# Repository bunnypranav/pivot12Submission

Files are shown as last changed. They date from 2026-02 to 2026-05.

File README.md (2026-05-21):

# PIVOT 12
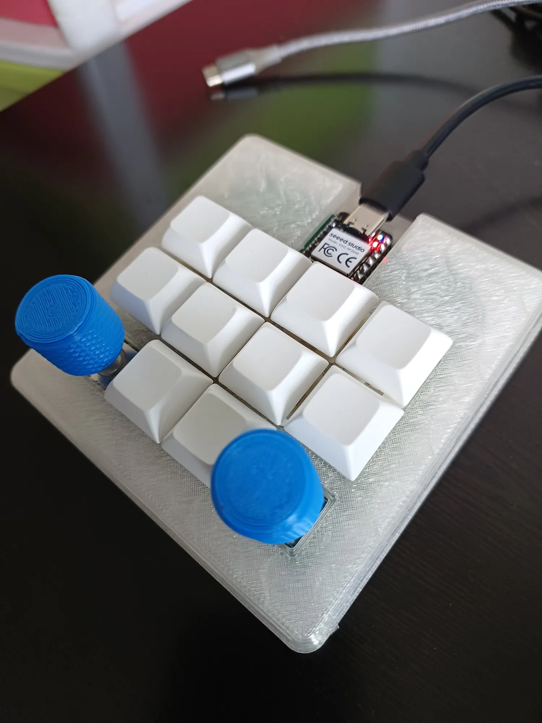
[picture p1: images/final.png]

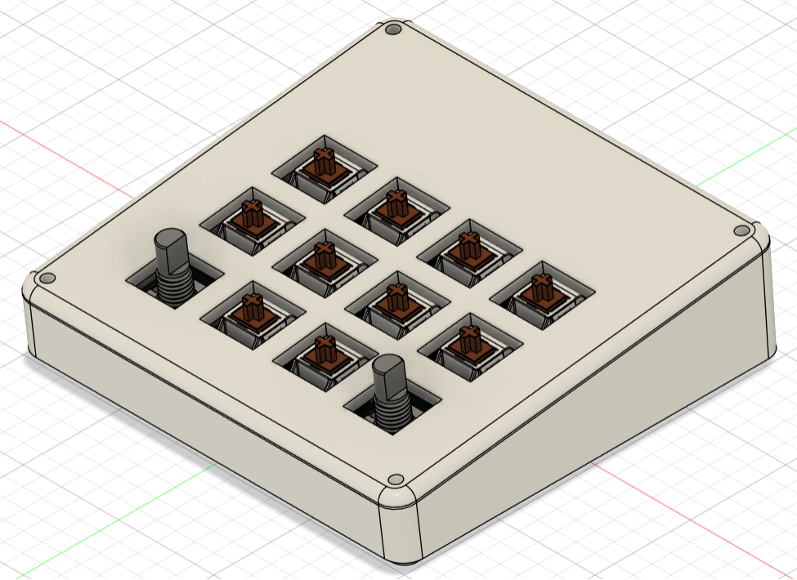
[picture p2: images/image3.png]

PIVOT 12 is a macropad with 10 MX switches and two rotary encoders and uses QMK firmware. It is aimed for productivity with a huge focus on the two dials. The name "PIVOT" signifies the rotary encoders as "pivotal" control elements (*pun intended*). The "12" in the name refers to the total number of inputs (10 switches + 2 rotary encoders) on the macropad.

A lot of what I do involves switching tabs, scrolling, navigating files, adjusting volume, and triggering similar shortcuts. Instead of just keys, I wanted something that felt like a control panel, and that is where the two dials come in. One usually handles navigation (like horizontal scrolling or tab switching), and the other handles adjustments (volume, zoom, etc.). Each encoder also has a push button, so they're more than just scroll wheels.

Building this was a great learning experience. I designed the PCB in KiCad and the case in Fusion 360. It was my first time designing a PCB, and I definitely struggled, and learned a lot. The case design was also a fun challenge, especially with the incline and making sure everything fit properly and was compatible with the PCB.

# Features
* 10 MX switches
* 2 Rotary Encoders
* Case with a 7° incline for ergonomic use

# PCB
*Made in KiCad*
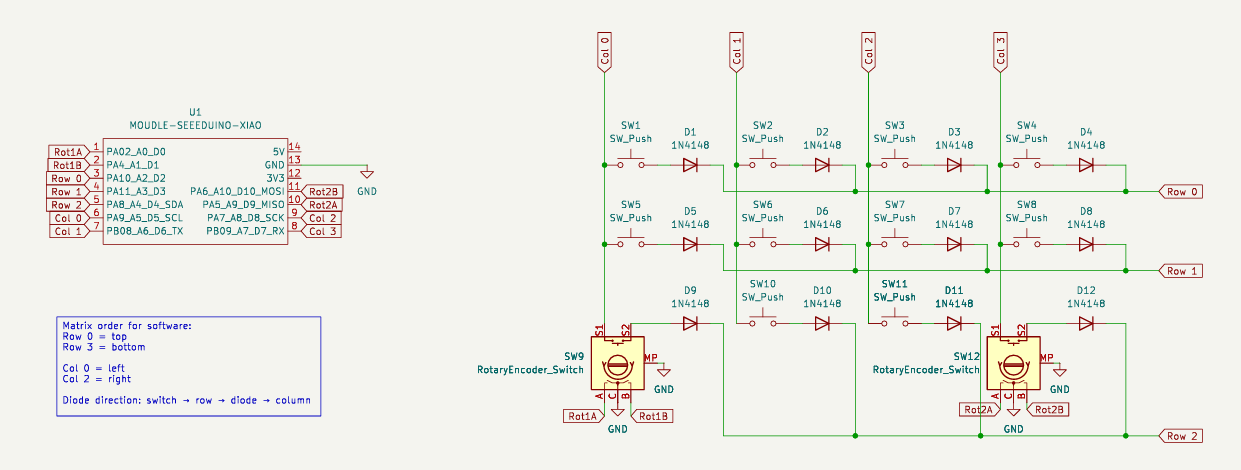
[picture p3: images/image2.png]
Schematic

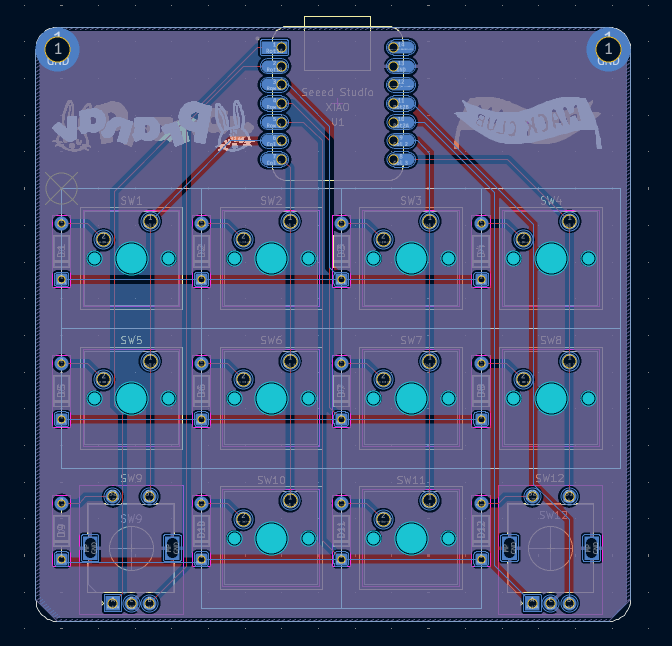
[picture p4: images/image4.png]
PCB Design

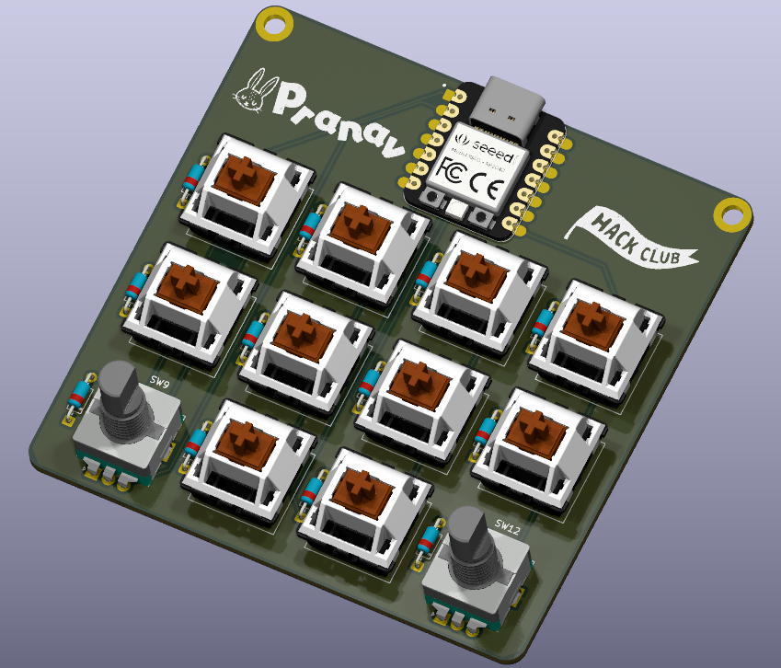
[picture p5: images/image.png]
3D PCB


# CAD Model
*Made in Fusion 360*
I didn't want a flat box, so I added a 7° incline. It's subtle, but it makes a noticeable difference when using it for long periods. The incline feels natural without making the device bulky.

For a video, see https://github.com/bunnypranav/pivot12Submission/raw/refs/heads/main/images/caseVid.mp4

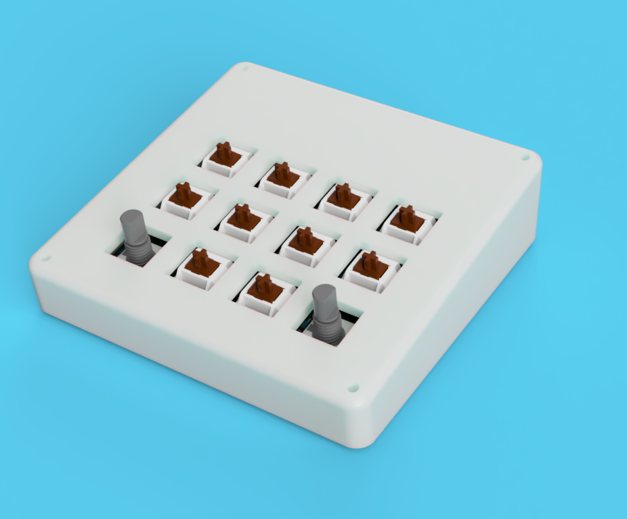
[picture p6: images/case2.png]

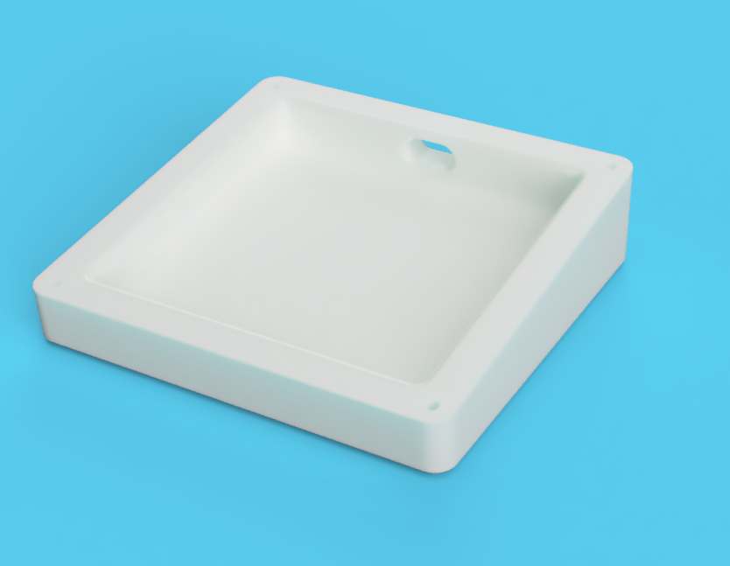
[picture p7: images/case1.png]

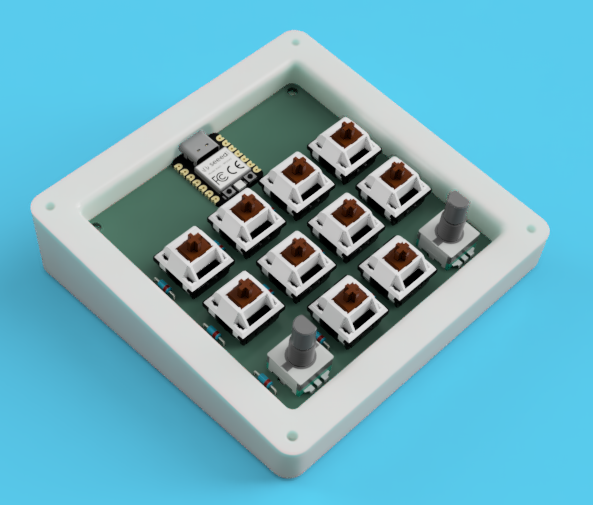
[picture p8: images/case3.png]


# BOM:
* 1x XIAO RP2040
* 10x Cherry MX Switches
* 10x DSA Keycaps
* 2x EC11 Rotary Encoder
* 12x 1N4148 DO-35 Diodes.
* 4x M3x5x4 Heatset inserts
* 4x M3x16mm SHCS Bolts
* 1x PCB: Costs about USD 14 with shipping
* 1x Case (4 printed parts)
  * Bottom base
  * Top plate
  * 2x Knurled knobs for dials

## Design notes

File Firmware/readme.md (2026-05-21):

# pivot12

pivot12

*A short description of the keyboard/project*

* Keyboard Maintainer: [Bunny Pranav](https://github.com/bunnypranav)
* Hardware Supported: *The PCBs, controllers supported*
* Hardware Availability: *Links to where you can find this hardware*

Make example for this keyboard (after setting up your build environment):

    make pivot12:default

Flashing example for this keyboard:

    make pivot12:default:flash

See the [build environment setup](https://docs.qmk.fm/#/getting_started_build_tools) and the [make instructions](https://docs.qmk.fm/#/getting_started_make_guide) for more information. Brand new to QMK? Start with our [Complete Newbs Guide](https://docs.qmk.fm/#/newbs).

## Bootloader

Enter the bootloader in 3 ways:

* **Bootmagic reset**: Hold down the key at (0,0) in the matrix (usually the top left key or Escape) and plug in the keyboard
* **Physical reset button**: Briefly press the button on the back of the PCB - some may have pads you must short instead
* **Keycode in layout**: Press the key mapped to `QK_BOOT` if it is available

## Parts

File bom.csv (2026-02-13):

Item | Quantity | Price with Shipping ($)
Seeed XIAO RP2040 | 1 | Part of KIT
MX-Style switches | 10 | Part of KIT
White blank DSA keycaps | 10 | Part of KIT
EC11 Rotary encoders | 2 | Part of KIT
1N4148 Diodes | 12 | Part of KIT
M3x5x4 Heatset inserts | 4 | Part of KIT
M3x16mm screws | 4 | Part of KIT
PCB | 1 | 14
Case (4 printed parts) | 1 | Printing legion, shipping about 1.1USD

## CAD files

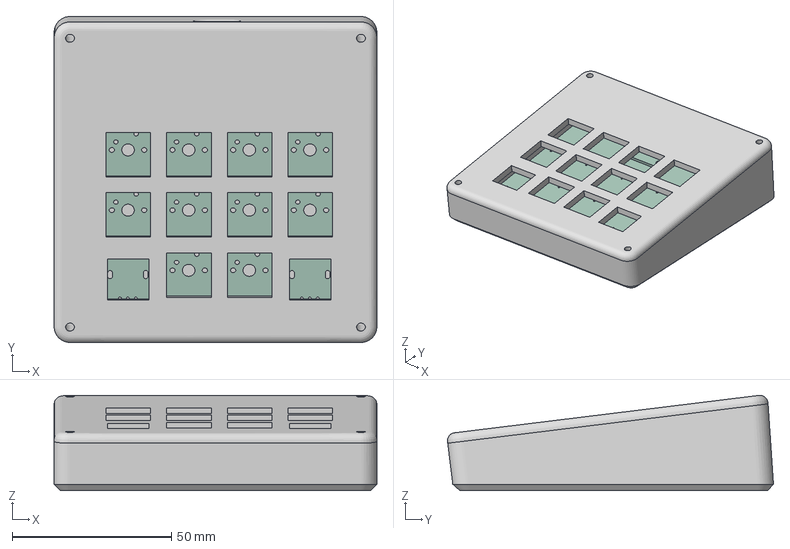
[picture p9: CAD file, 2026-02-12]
CAD/PIVOT-12-Case.3mf
101.4 x 102.4 x 29.9 mm
Base
PCB(NoPrint)
Plate

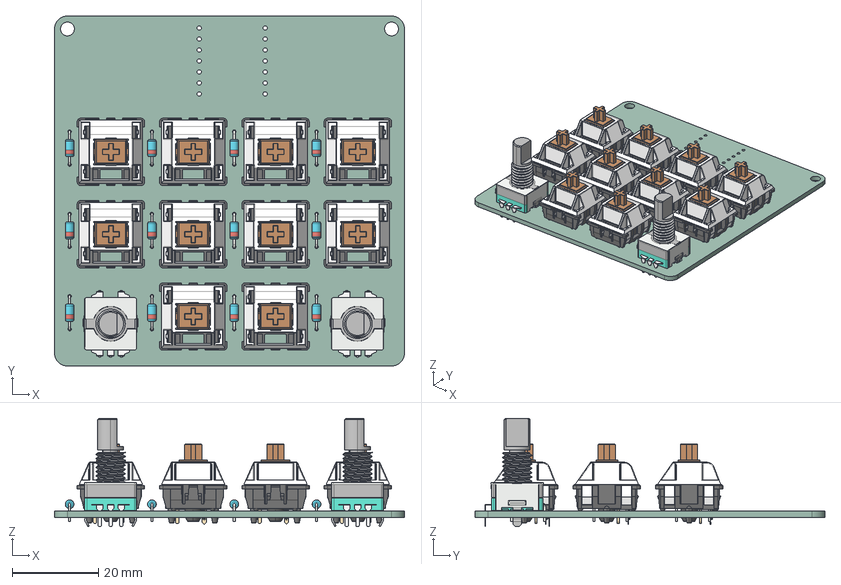
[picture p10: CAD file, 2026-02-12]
PCB/pivot12PCB.step
81.0 x 81.0 x 25.1 mm
D_DO-35_SOD27_P7.62mm_Horizontal x 12
SW_Cherry_MX_1.00u_PCB x 10
Rotary x 2
pivot12KiCadProject_PCB

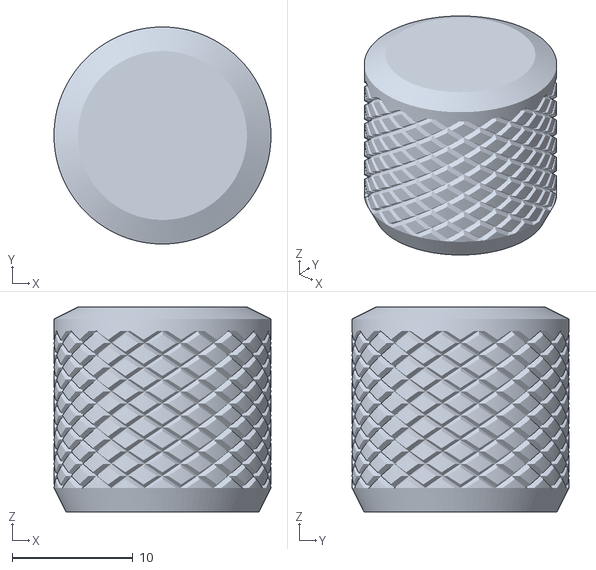
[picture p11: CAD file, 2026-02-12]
production/Knob(x2).stl
18.0 x 18.0 x 17.0

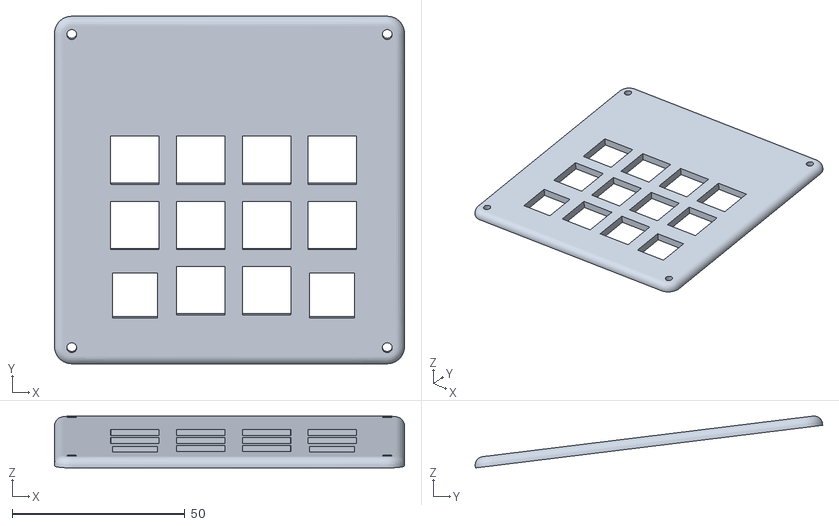
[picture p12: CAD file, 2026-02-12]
production/Top.stl
101.4 x 100.7 x 15.0

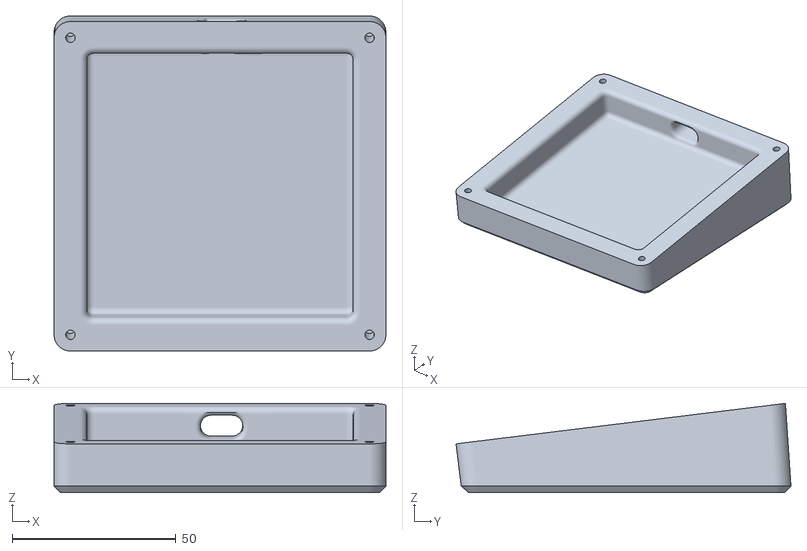
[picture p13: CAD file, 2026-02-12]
production/Base.stl
101.4 x 102.3 x 27.2

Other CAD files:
CAD/PIVOT-12-Case.f3z

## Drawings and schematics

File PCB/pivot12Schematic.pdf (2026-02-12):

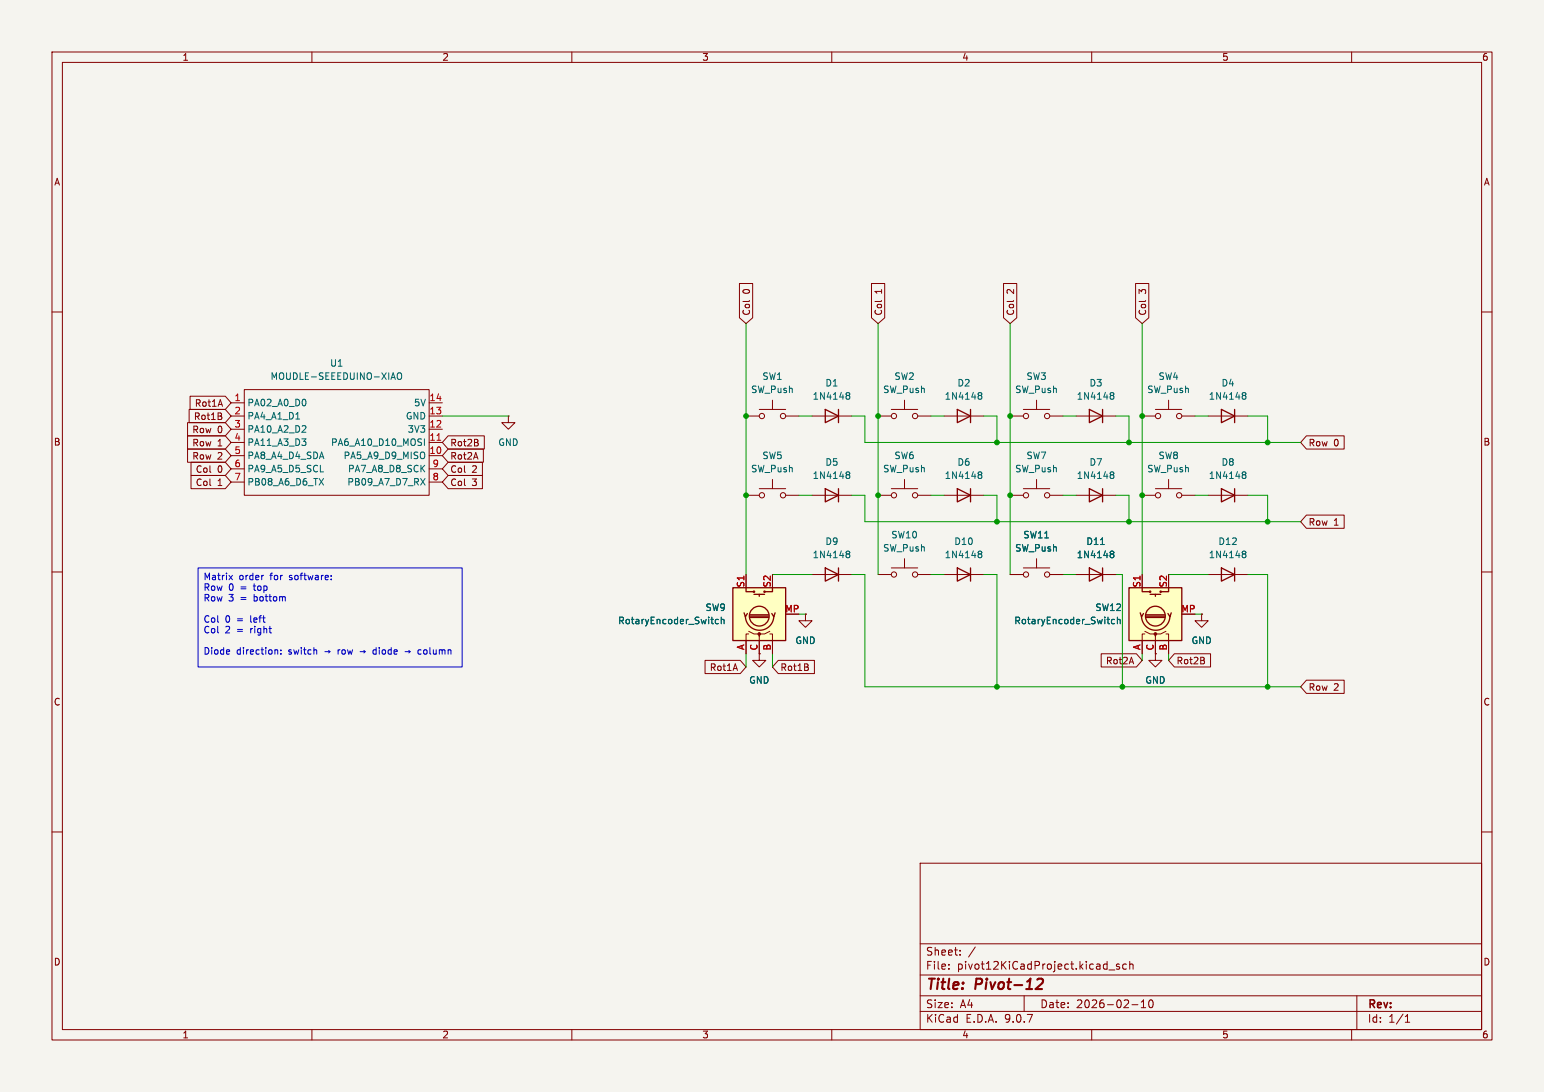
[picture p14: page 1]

Row 1 Rot1B Rot1A Row 0 Row 2 Col 1 Col 0 Matrix order for software: Row 0 = top Row 3 = bottom

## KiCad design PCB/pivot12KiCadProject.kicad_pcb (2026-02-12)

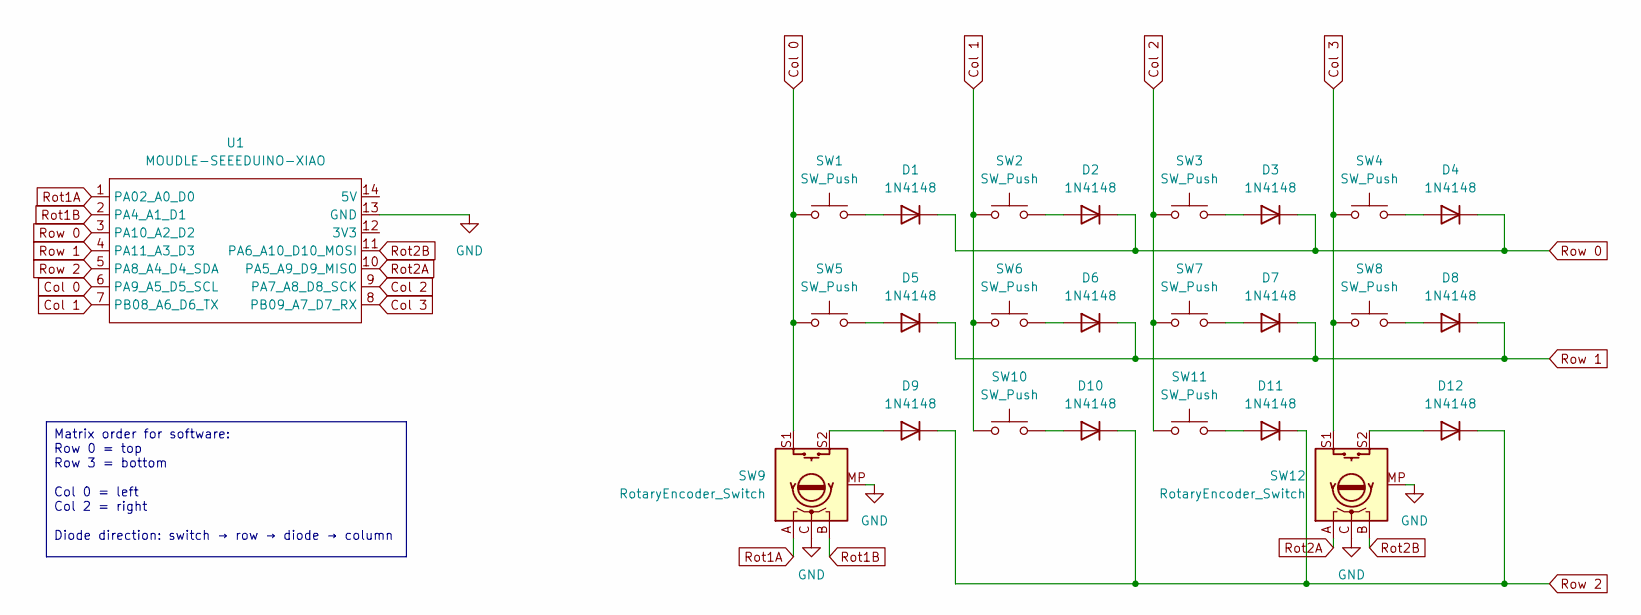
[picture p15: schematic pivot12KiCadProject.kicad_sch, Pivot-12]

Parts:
D1, D2, D3, D4, D5, D6, D7, D8, D9, D10, D11, D12: 1N4148; D_DO-35_SOD27_P7.62mm_Horizontal
SW1, SW2, SW3, SW4, SW5, SW6, SW7, SW8, SW10, SW11: SW_Push; SW_Cherry_MX_1.00u_PCB
SW9, SW12: RotaryEncoder_Switch; RotaryEncoder_Alps_EC11E-Switch_Vertical_H20mm
U1: MOUDLE-SEEEDUINO-XIAO; XIAO-Generic-Hybrid-14P-2.54-21X17.8MM

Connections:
Col 0: SW1.1, SW5.1, SW9.S1, U1.6 (PA9_A5_D5_SCL)
Col 1: SW2.1, SW6.1, SW10.1, U1.7 (PB08_A6_D6_TX)
Col 2: SW3.1, SW7.1, SW11.1, U1.9 (PA7_A8_D8_SCK)
Col 3: SW4.1, SW8.1, SW12.S1, U1.8 (PB09_A7_D7_RX)
GND: SW9.C, SW9.MP, SW12.C, SW12.MP, U1.13 (GND)
unnamed: D1.2 (A), SW1.2
unnamed: D2.2 (A), SW2.2
unnamed: D3.2 (A), SW3.2
unnamed: D4.2 (A), SW4.2
unnamed: D5.2 (A), SW5.2
unnamed: D6.2 (A), SW6.2
unnamed: D7.2 (A), SW7.2
unnamed: D8.2 (A), SW8.2
unnamed: D9.2 (A), SW9.S2
unnamed: D10.2 (A), SW10.2
unnamed: D11.2 (A), SW11.2
unnamed: D12.2 (A), SW12.S2
Rot1A: SW9.A, U1.1 (PA02_A0_D0)
Rot1B: SW9.B, U1.2 (PA4_A1_D1)
Rot2A: SW12.A, U1.10 (PA5_A9_D9_MISO)
Rot2B: SW12.B, U1.11 (PA6_A10_D10_MOSI)
Row 0: D1.1 (K), D2.1 (K), D3.1 (K), D4.1 (K), U1.3 (PA10_A2_D2)
Row 1: D5.1 (K), D6.1 (K), D7.1 (K), D8.1 (K), U1.4 (PA11_A3_D3)
Row 2: D9.1 (K), D10.1 (K), D11.1 (K), D12.1 (K), U1.5 (PA8_A4_D4_SDA)

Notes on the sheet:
Matrix order for software: Row 0 = top Row 3 = bottom Col 0 = left Col 2 = right Diode direction: switch → row → diode → column

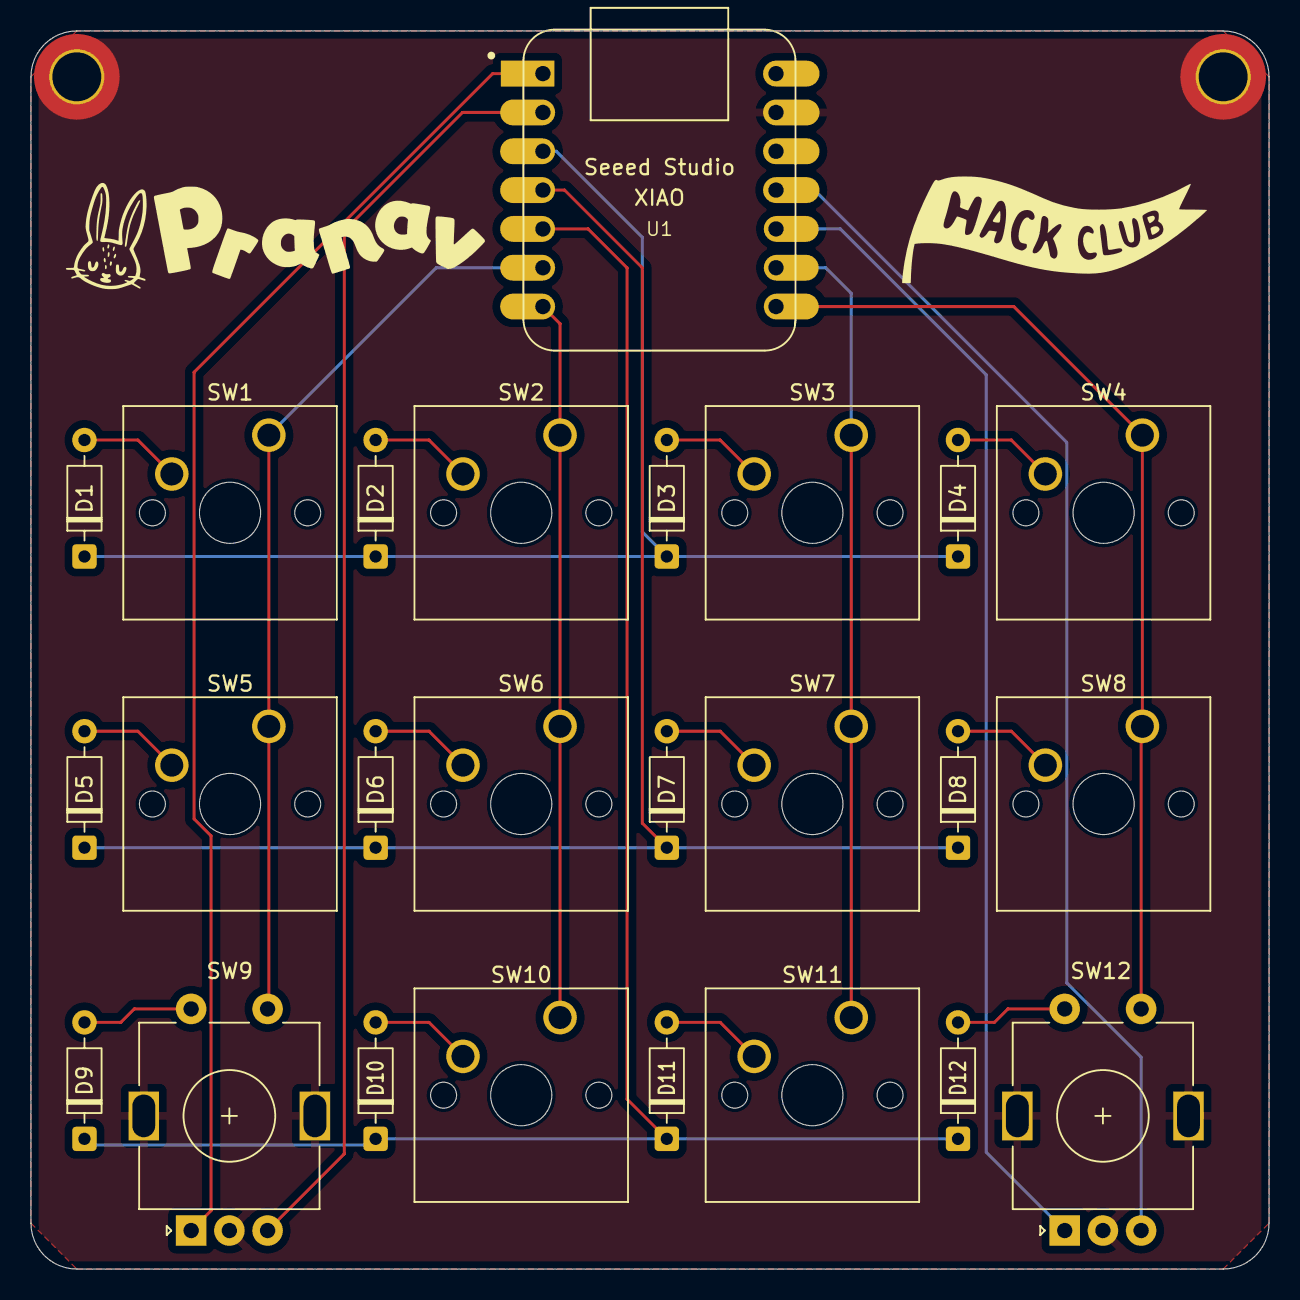
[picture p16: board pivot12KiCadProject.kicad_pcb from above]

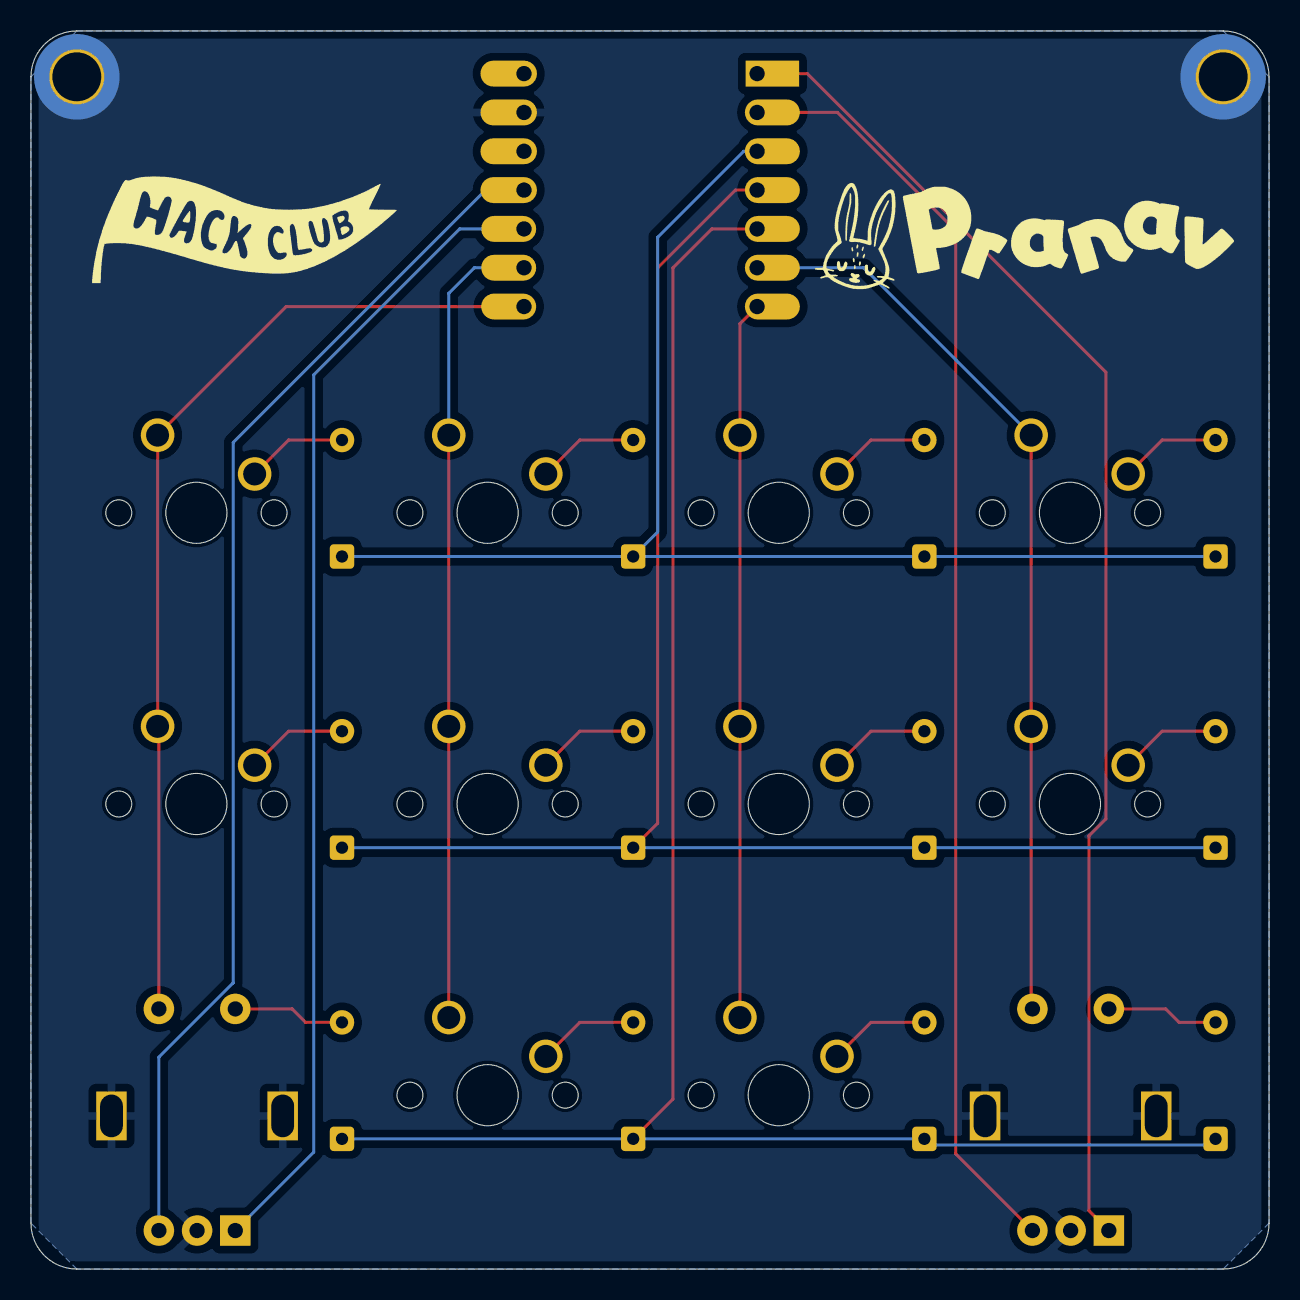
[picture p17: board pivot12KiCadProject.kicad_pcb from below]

Board: 2 copper layers, 81.0 x 81.0 mm, 29 parts (2 on the bottom side), 24 nets.

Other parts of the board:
Logo1, Logo1#2: LOGO
Mount2, Mount2#2: LOGO

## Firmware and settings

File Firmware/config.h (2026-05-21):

#pragma once

#define MATRIX_ROWS 3
#define MATRIX_COLS 4

#define MATRIX_ROW_PINS {GP28, GP29, GP6}
#define MATRIX_COL_PINS {GP7, GP0, GP2, GP1}

#define ENCODERS_PAD_A {GP27, GP3}
#define ENCODERS_PAD_B {GP26, GP4}

#define DIODE_DIRECTION COL2ROW

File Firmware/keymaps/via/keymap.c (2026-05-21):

#include QMK_KEYBOARD_H

const uint16_t PROGMEM keymaps[][MATRIX_ROWS][MATRIX_COLS] = {[0] = LAYOUT(KC_TRNS, KC_TRNS, KC_TRNS, KC_TRNS, KC_TRNS, KC_TRNS, KC_TRNS, KC_TRNS, KC_TRNS, KC_TRNS, KC_TRNS, KC_TRNS), [1] = LAYOUT(KC_TRNS, KC_TRNS, KC_TRNS, KC_TRNS, KC_TRNS, KC_TRNS, KC_TRNS, KC_TRNS, KC_TRNS, KC_TRNS, KC_TRNS, KC_TRNS), [2] = LAYOUT(KC_TRNS, KC_TRNS, KC_TRNS, KC_TRNS, KC_TRNS, KC_TRNS, KC_TRNS, KC_TRNS, KC_TRNS, KC_TRNS, KC_TRNS, KC_TRNS), [3] = LAYOUT(KC_TRNS, KC_TRNS, KC_TRNS, KC_TRNS, KC_TRNS, KC_TRNS, KC_TRNS, KC_TRNS, KC_TRNS, KC_TRNS, KC_TRNS, KC_TRNS)};

const uint16_t PROGMEM encoder_map[][NUM_ENCODERS][2] = {[0] =
                                                             {
                                                                 {KC_TRNS, KC_TRNS}, // encoder 0
                                                                 {KC_TRNS, KC_TRNS}  // encoder 1
                                                             },
                                                         [1] = {{KC_TRNS, KC_TRNS}, {KC_TRNS, KC_TRNS}},
                                                         [2] = {{KC_TRNS, KC_TRNS}, {KC_TRNS, KC_TRNS}},
                                                         [3] = {{KC_TRNS, KC_TRNS}, {KC_TRNS, KC_TRNS}}};

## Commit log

2026-02-13 Update README with more info Add BOM.csv
    [bom.csv, designators.csv, positions.csv]
2026-02-13 Add CAD with full PCB, STEP file, and related images in README
